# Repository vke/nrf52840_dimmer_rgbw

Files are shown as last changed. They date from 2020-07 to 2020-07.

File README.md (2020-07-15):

# KiCad source files for nrf52840-based RGBW dimmer project.

Available firmware:

https://github.com/vke/nrf52840_dimmer_rgbw_thread (Thread/OpenThread)

https://github.com/vke/nrf52840_dimmer_rgbw_zigbee (ZigBee, incomplete due to a lot of bugs in ZBOSS ZigBee SDK)

Motherboard with nrf52840 (version 2.05):

https://github.com/vke/EFEKTA-nRF52840-MINI-DEV-BOARD

# Images:

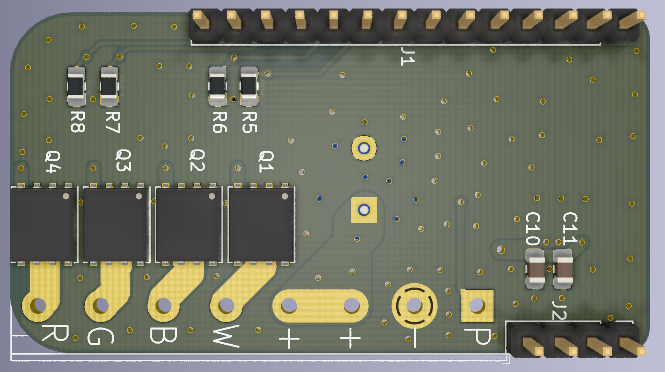
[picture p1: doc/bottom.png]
bottom

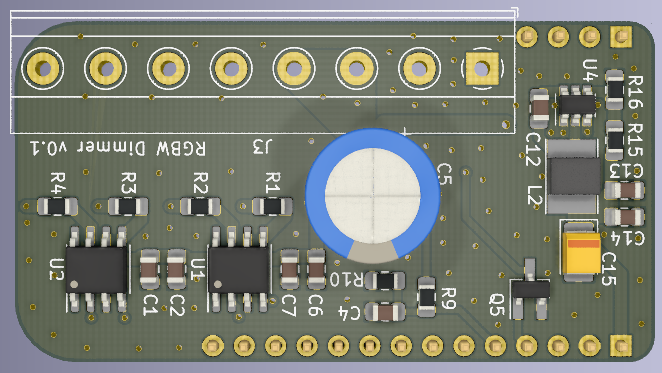
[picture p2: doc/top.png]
top

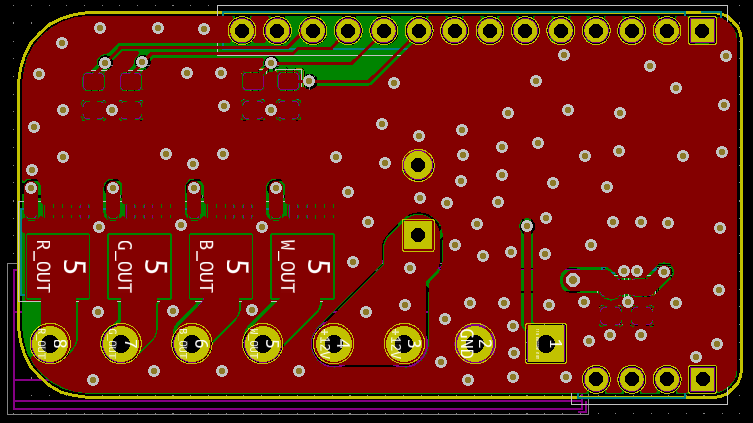
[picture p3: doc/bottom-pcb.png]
bottom pcb

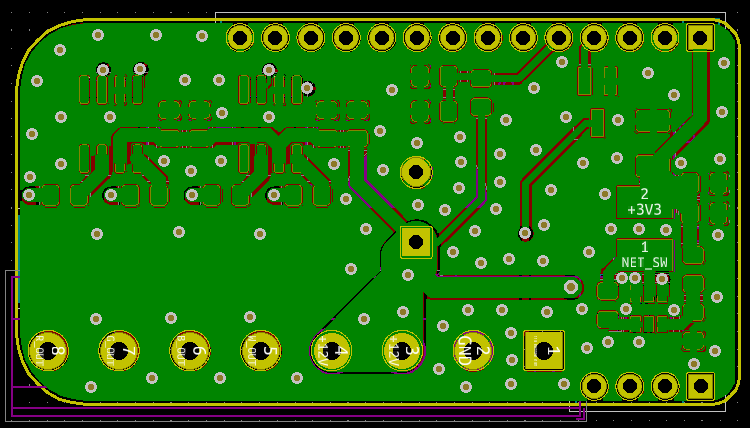
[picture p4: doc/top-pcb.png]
top pcb


# BOM:

Q5; "digital" transistor:

https://lcsc.com/product-detail/Digital-Transistors_Leshan-Radio-LMUN2233LT1G_C12777.html

R10, R16; 0805, 1%, 22.1K:

https://lcsc.com/product-detail/Chip-Resistor-Surface-Mount_UNI-ROYAL-Uniroyal-Elec-0805W8F2212T5E_C17552.html

Q1-Q4; any suitable mosfet:

https://lcsc.com/product-detail/MOSFET_Infineon-Technologies-BSC067N06LS3G_C24199.html

https://lcsc.com/product-detail/MOSFET_Infineon-Technologies-BSC022N04LS_C148266.html

C4; 0805, 1uF:

https://lcsc.com/product-detail/Multilayer-Ceramic-Capacitors-MLCC-SMD-SMT_Samsung-Electro-Mechanics-CL21B105KBFNNNE_C28323.html

C1, C6, C10, C14; 0805, 4.7 uF:

https://lcsc.com/product-detail/Multilayer-Ceramic-Capacitors-MLCC-SMD-SMT_TDK-C2012X7R1V475KT000E_C76651.html

https://lcsc.com/product-detail/Multilayer-Ceramic-Capacitors-MLCC-SMD-SMT_Samsung-Electro-Mechanics-CL21A475KBQNNNE_C98192.html

https://lcsc.com/product-detail/Multilayer-Ceramic-Capacitors-MLCC-SMD-SMT_Murata-Electronics-GRM21BC71H475KE11L_C162320.html

C5; 390 uF, 25V:

https://lcsc.com/product-detail/Solid-Polymer-Electrolytic-Capacitor_NCC-Nippon-Chemi-Con-APSG250ELL391MJB5S_C133441.html

C2, C7, C11, C12, C13; 0805, 0.1 uF:

https://lcsc.com/product-detail/Multilayer-Ceramic-Capacitors-MLCC-SMD-SMT_Samsung-Electro-Mechanics-CL21B104KBFNNNE_C136621.html

C15; 47 uF, 10V:

https://lcsc.com/product-detail/Tantalum-Capacitors_KEMET-T520B476M010ATE035_C141441.html

U1, U2; TC4427 mosfet drivers:

https://lcsc.com/product-detail/MOS-Drivers_Microchip-Tech-TC4427COA713_C144205.html

R9, R15; 0805, 1%, 100K:

https://lcsc.com/product-detail/Chip-Resistor-Surface-Mount_UNI-ROYAL-Uniroyal-Elec-0805W8F1003T5E_C149504.html

U4; TPS54202 step-down converter:

https://lcsc.com/product-detail/DC-DC-Converters_Texas-Instruments-TPS54202DDCR_C191884.html

R1-R4; 0805, 200R:

https://lcsc.com/product-detail/Chip-Resistor-Surface-Mount_UNI-ROYAL-Uniroyal-Elec-0805W8J0201T5E_C25292.html

R5-R8; 0805, 10K:

https://lcsc.com/product-detail/Chip-Resistor-Surface-Mount_SANYEAR-SY0805JN10KP_C380776.html

L2; 10uH 1.5A:

https://lcsc.com/product-detail/Inductors-SMD_GLE-GCNR4030-100MC_C439346.html

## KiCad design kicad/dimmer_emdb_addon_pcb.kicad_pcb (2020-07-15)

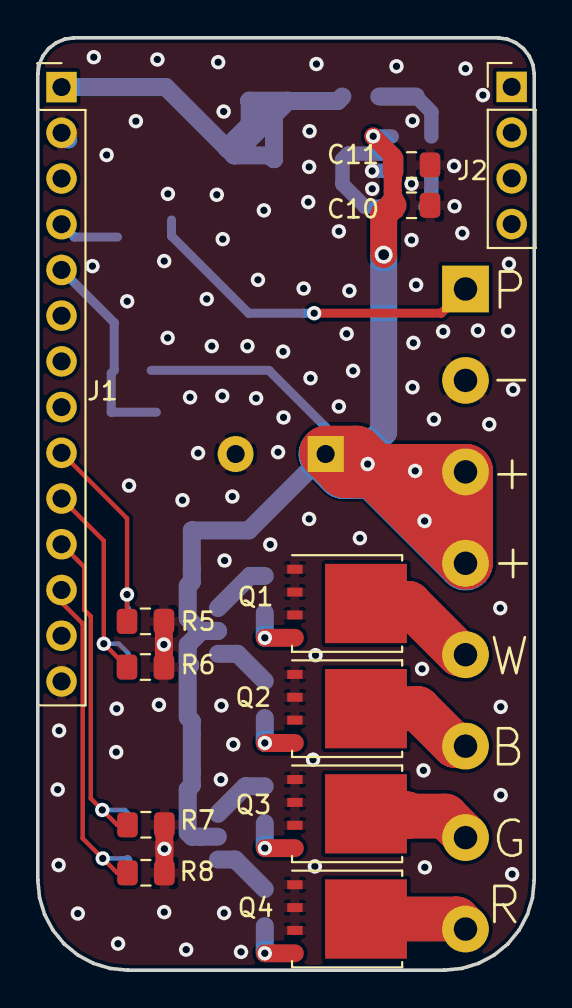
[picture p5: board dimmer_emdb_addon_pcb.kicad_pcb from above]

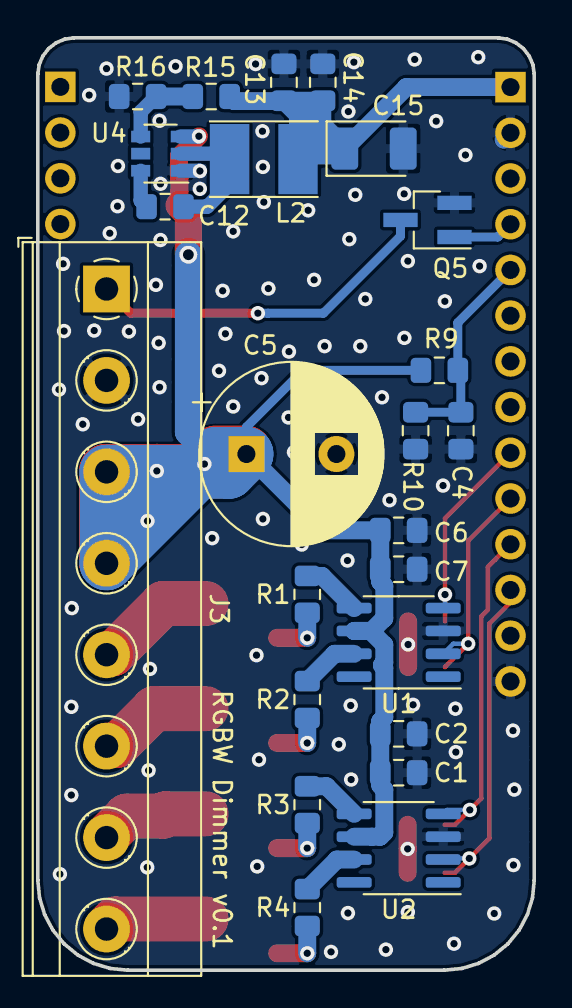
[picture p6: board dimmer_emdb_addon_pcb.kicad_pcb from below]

Board: 2 copper layers, 27.6 x 51.8 mm, 36 parts (24 on the bottom side), 25 nets.

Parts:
C1, C6, C10, C14: 4.7uF; C_0805_2012Metric_Pad1.15x1.40mm_HandSolder
C2, C7, C11, C12, C13: 0.1uF; C_0805_2012Metric_Pad1.15x1.40mm_HandSolder
C4: 1uF; C_0805_2012Metric_Pad1.15x1.40mm_HandSolder
C5: 100uF; CP_Radial_D10.0mm_P5.00mm
C15: 47uF; CP_EIA-3528-21_Kemet-B_Pad1.50x2.35mm_HandSolder
J1: Conn_01x14_Male; Pin_Header_Straight_1x14_Pitch2.54mm
J2: Conn_01x04_Male; PinHeader_1x04_P2.54mm_Vertical
J3: Screw_Terminal_01x08; TerminalBlock_Phoenix_MKDS-1,5-8-5.08_1x08_P5.08mm_Horizont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
L2: 10uH; L_Taiyo-Yuden_NR-40xx_HandSoldering
Q1, Q2, Q3, Q4: BSC067N06LS3G; TDSON-8-1
Q5: LMUN2233LT1G; SOT-23_Handsoldering
R1, R2, R3, R4: 50R; R_0805_2012Metric_Pad1.15x1.40mm_HandSolder
R5, R6, R7, R8: 10K; R_0805_2012Metric_Pad1.15x1.40mm_HandSolder
R9, R15: 100K; R_0805_2012Metric_Pad1.15x1.40mm_HandSolder
R10: 22K; R_0805_2012Metric_Pad1.15x1.40mm_HandSolder
R16: 22K1; R_0805_2012Metric_Pad1.15x1.40mm_HandSolder
U1, U2: TC4427; SOIC-8_3.9x4.9mm_P1.27mm
U4: TPS54202DDCR; SOT-23-6

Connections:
12V_Sense: C4.1, J1.5, R9.2, R10.1
+3V3: C13.1, C14.1, C15.1, J1.1, L2.2, R15.1
+12V: C1.1, C2.1, C5.1, C6.1, C7.1, C10.1, C11.1, J3.3, J3.4, R9.1, U1.6, U2.6, U4.3
/B_IN: J1.10, R6.1, U1.2
/B_OUT: J3.6, Q2.5
/G_IN: J1.11, R7.1, U2.4
/G_OUT: J3.7, Q3.5
/NET_BOOT: C12.2, U4.6
/NET_FB: R15.2, R16.1, U4.4
/NET_SW: C12.1, L2.1, U4.2
/PSU_ENABLE_OUT: J3.1, Q5.3
/R_IN: J1.12, R8.1, U2.2
/R_OUT: J3.8, Q4.5
/W_IN: J1.9, R5.1, U1.4
/W_OUT: J3.5, Q1.5
GND: C1.2, C2.2, C4.2, C5.2, C6.2, C7.2, C10.2, C11.2, C13.2, C14.2, C15.2, J1.2, J1.14, J3.2, Q1.1, Q1.2, Q1.3, Q2.1, Q2.2, Q2.3, Q3.1, Q3.2, Q3.3, Q4.1, Q4.2, Q4.3, Q5.2, R5.2, R6.2, R7.2, R8.2, R10.2, R16.2, U1.3, U2.3, U4.1
unnamed: Q1.4, R1.1
unnamed: Q2.4, R2.1
unnamed: Q3.4, R3.1
unnamed: Q4.4, R4.1
unnamed: R1.2, U1.5
unnamed: R2.2, U1.7
unnamed: R3.2, U2.5
unnamed: R4.2, U2.7
PSU_Enable: J1.4, Q5.1

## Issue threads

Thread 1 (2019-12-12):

Color temperature

codegraffiti, 2019-12-12:
Hello,
I am trying to build custom bulb which can control brightness and color temperature. Please can you help me how to modify the code to achieve this. my device uses pwm to control brightness and color temperature.

Best regards,
Chandan

codegraffiti, 2019-12-12:
do you have marketplace or any other way so that I can contribute to your efforts. I can for sure buy you few beers

vke, 2020-01-10:
@codegraffiti Hi! Sorry, I didn’t even know that someone could write issues here, so I didn’t notice your messages.

As about color temperature: I didn't yet tried to write such code myself, but you can check `ble_zigbee_dynamic_color_light_bulb_thingy` example from Nordic's Zigbee SDK. At least they filling default values for color temp.

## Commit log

2020-07-15 Initial release, split hw and sw parts of project
    [dimmer_emdb_addon_pcb.kicad_pcb, dimmer_emdb_addon_pcb.sch]
2020-07-15 PCB images + BOM
    [dimmer_emdb_addon_pcb.kicad_pcb, dimmer_emdb_addon_pcb.sch]
